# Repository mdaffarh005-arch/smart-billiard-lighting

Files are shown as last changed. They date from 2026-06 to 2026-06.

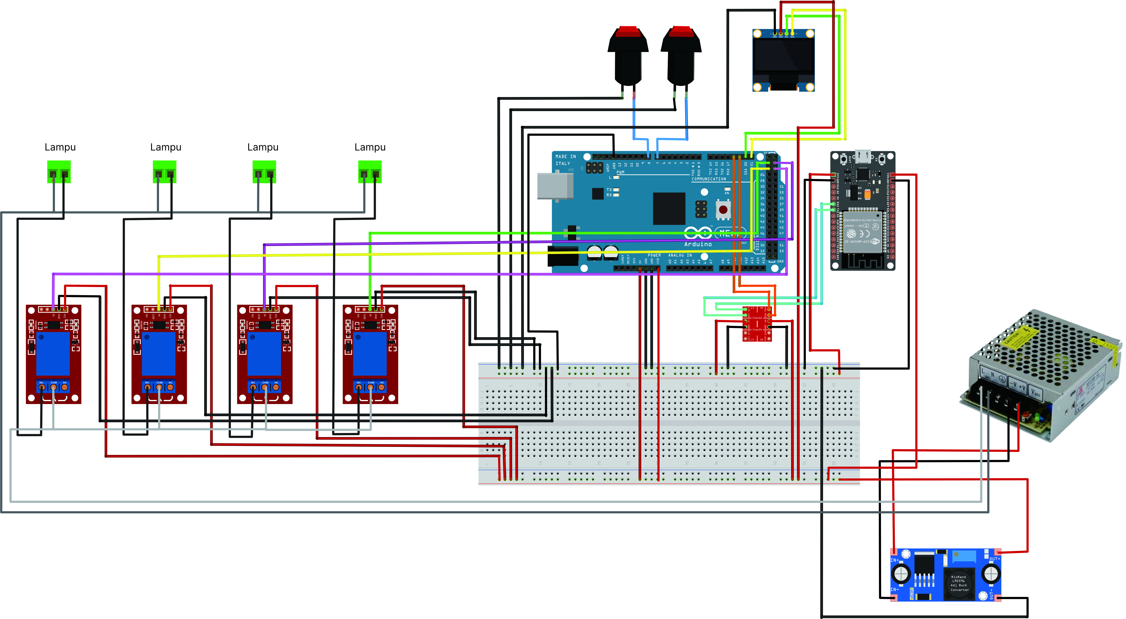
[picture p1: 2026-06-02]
Hardware/wiring-diagram-smart-billiard-lighting.jpg

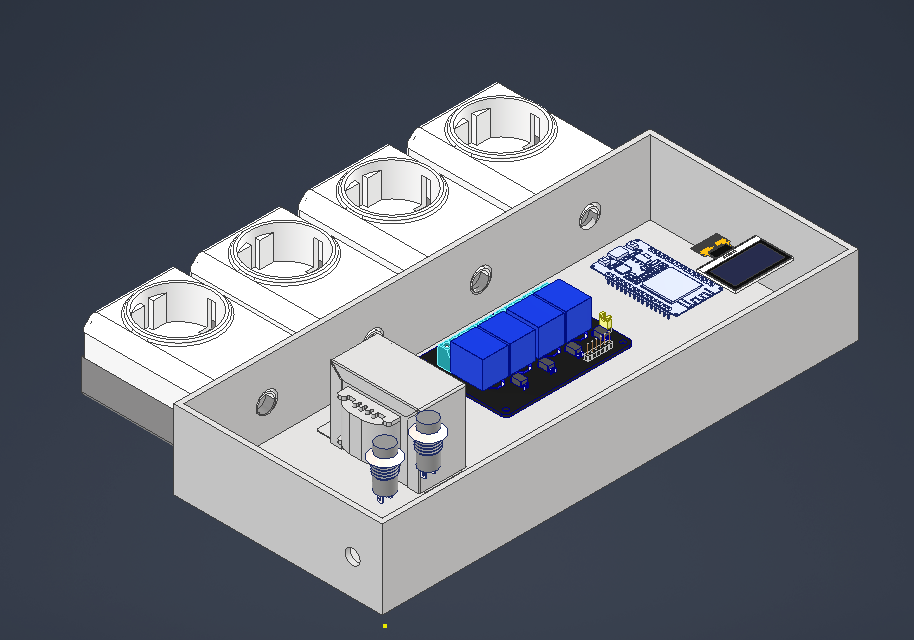
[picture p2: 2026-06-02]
3D Design/TOP Right Back Without Box Cover View.png

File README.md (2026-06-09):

# 🎱 Smart Billiard Lighting & Billing System

> Integrasi Billing, Timer, dan Kontrol Lampu dalam Satu Sistem

Sistem berbasis ATmega2560 yang mengintegrasikan kontrol lampu meja biliar, timer permainan, dan perhitungan biaya sewa dalam satu dashboard kasir. Proyek ini bertujuan meningkatkan efisiensi operasional, mengurangi human error, dan meminimalkan pemborosan energi listrik.

---

📖 Overview

Smart Billiard Lighting & Billing System merupakan solusi otomatisasi untuk membantu pengelolaan arena biliar. Sistem menghubungkan aplikasi kasir dengan mikrokontroler ATmega2560 melalui komunikasi serial UART sehingga status penggunaan meja dapat dipantau dan dikendalikan secara real-time.

Selain mengontrol lampu meja secara otomatis, sistem juga mampu mencatat durasi bermain, menghitung biaya sewa berdasarkan tarif per menit, serta menyimpan riwayat transaksi.

---

🎯 Objectives
* **Mengurangi pemborosan energi listrik pada meja biliar.**
* **Mengotomatisasi pencatatan durasi bermain pelanggan.**
* **Menghitung biaya sewa secara otomatis berdasarkan waktu penggunaan.**
* **Mengurangi human error dalam operasional arena biliar.**
* **Meningkatkan efisiensi pengelolaan meja dan transaksi kasir.**

✨ Features

⏱ Real-Time Timer

Menampilkan durasi bermain setiap meja secara real-time.

💰 Flexible Pricing

Harga per jam dapat diatur sesuai kebutuhan operasional.

🧮 Automatic Billing

Total biaya dihitung otomatis berdasarkan durasi penggunaan meja.

💡 Smart Lighting Control

Lampu meja menyala dan mati mengikuti status penggunaan meja.

🎛 Manual & Automatic Mode

Mendukung pengoperasian secara otomatis maupun manual.

📊 Monitoring Dashboard

Menampilkan status meja, durasi bermain, dan total biaya dalam satu tampilan.

💲Income Automatic Monitoring

Dapat menghitung otomatis total pendapatan yang didapatkan.

```mermaid
flowchart TD
    A[Kasir Dashboard]
    B[Serial Communication]
    C[ATmega2560]
    D[Timer]
    E[Billing]
    F[Relay]
    G[Durasi Bermain]
    H[Total Biaya]
    I[Lampu Meja]

    A --> B
    B --> C
    C --> D
    C --> E
    C --> F
    D --> G
    E --> H
    F --> I
```

Main Workflow
* **Kasir memilih meja yang akan digunakan.**
* **Kasir mengatur tarif per menit.**
* **Sistem mengaktifkan timer dan lampu meja.**
* **Durasi bermain dihitung secara real-time.**
* **Sistem menghitung biaya berdasarkan durasi bermain.**
* **Saat sesi berakhir, lampu dimatikan otomatis.**
* **Riwayat transaksi disimpan pada sistem.**

## 👥 Tim Pengembang & Kontributor

| No | Nama Lengkap | NRP | Peran Utama & Fokus Jobdesk | GitHub Profile | Status Kontribusi |
| :---: | :--- | :---: | :--- | :--- | :---: |
| **1** | **Muh. Daffa Rizaldy H.** | 2124600004 | **Project Manager**<br>• Manajemen linimasa & koordinasi integrasi sistem | [@mdaffarh005-arch](https://github.com/mdaffarh005-arch) | 🟢 Done Commit |
| **2** | **Moh Harudin Ali** | 2124600008 | **Software Engineer (Firmware)**<br>• Pengodean logika kontrol pemutusan relay | [@Harudin31](https://github.com/Harudin31) | 🟢 Done Commit |
| **3** | **Achmad Rafie Febriansyah** | 2124600011 | **3D Designer**<br>• Pemodelan objek 3D casing box komponen | [@rafiefebriansyahh](https://github.com/rafiefebriansyahh) | 🟢 Done Commit |
| **4** | **Imam Syaifudin** | 2124600015 | **Hardware Engineer**<br>• Perancangan skematik dan desain PCB | [@imam603](https://github.com/imam603) | 🟢 Done Commit |
| **5** | **Muhammad Abdi Muhyi Umam** | 2124600023 | **UI/UX Designer**<br>• Perancangan interface dashboard web kasir | [@abdiemuhyi](https://github.com/abdiemuhyi) | 🟢 Done Commit |
| **6** | **Gandhi Husain Albana** | 2124600026 | **Software Engineer (Web & DB)**<br>• Pengembangan database & komunikasi serial | [@gandhialbana-art](https://github.com/gandhialbana-art) | 🟢 Done Commit |

---

## 📊 To Do List

### 🟢 Complete

* **[x]Repository setup**
* **[x]Git workflow configuration**
* **[x]Initial system design**
* **[x]Initial system planning**
* **[x]Mind map & root cause analysis**
* **[x]Team collaboration setup**
* **[x]Dashboard development**
* **[x]Automatic billing calculation**
* **[x]Relay control integration**
* **[x]Hardware assembly**
* **[x]PCB design**

🌍 SDGs Impact

SDG 7 – Affordable and Clean Energy

Meningkatkan efisiensi penggunaan energi melalui sistem kontrol lampu otomatis.

SDG 12 – Responsible Consumption and Production

Mendorong penggunaan sumber daya listrik yang lebih efisien dan bertanggung jawab.

🛠 Development Tools

* **ATmega2560**
* **Wokwi Simulator**
* **VS Code**
* **GitHub**
* **EasyEDA**
* **Figma**
* **Python Tkinter**

📚 Course Information

* **Course: Microcontroller AVR**
* **Project Type: Embedded System & IoT Project**
* **Repository: Smart Billiard Lighting & Billing System**

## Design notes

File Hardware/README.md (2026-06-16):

# 💡 Smart Billiard Lighting

## 📂 Folder Hardware

# Isi Folder
- File Schematic (EasyEDA)
- File PCB Layout
- 3D PCB View
- Wiring Diagram (Fritzing)

# Arduino Mega 2560
Berfungsi sebagai pengendali utama sistem:
- Mengelola logika program billing
- Mengontrol relay lampu meja biliar
- Membaca input tombol ON/OFF
- Mengirim dan menerima data dengan ESP32
- Mengendalikan tampilan OLED

# ESP32 DevKitC
Digunakan sebagai modul komunikasi:
- Koneksi Wi-Fi ke aplikasi atau server
- Monitoring status sistem secara real-time
- Pertukaran data dengan Arduino Mega melalui UART

# Logic Level Converter
Digunakan untuk menyesuaikan level tegangan komunikasi:
- Konversi sinyal 5V ↔ 3.3V
- Melindungi ESP32 dari level tegangan Arduino Mega

# Relay Module 1 Channel
Digunakan untuk mengendalikan lampu meja biliar:
- Relay 1 → Lampu Meja 1
- Relay 2 → Lampu Meja 2
- Relay 3 → Lampu Meja 3
- Relay 4 → Lampu Meja 4
- Isolasi antara rangkaian kontrol dan beban lampu

# OLED Display SSD1306
Berfungsi sebagai tampilan informasi sistem:
- Status koneksi
- Informasi billing
- Waktu bermain
- Status lampu meja

# Push Button
Digunakan sebagai kontrol manual:
- Tombol ON untuk mengaktifkan sistem atau fungsi tertentu
- Tombol OFF untuk menghentikan atau membatalkan proses

# Power Supply
Rangkaian catu daya terdiri dari:
- Input tegangan 12V DC

# Modul step-down LM2596
- Output 5V untuk Arduino, relay, dan periferal
- Output 3.3V untuk ESP32 dan rangkaian logika

# Koneksi Sistem
- Komunikasi Arduino Mega ↔ ESP32
- TX2 Arduino (D16) → RX2 ESP32 melalui Level Converter
- RX2 Arduino (D17) → TX2 ESP32 melalui Level Converter
- Komunikasi menggunakan protokol UART Serial
  
OLED Display
- SDA → D20 (SDA)
- SCL → D21 (SCL)
Menggunakan komunikasi I2C

Input Push Button
- Tombol ON → D7
- Tombol OFF → D8
  
Output Relay
- Relay 1 → D22
- Relay 2 → D23
- Relay 3 → D24
- Relay 4 → D25

# Desain PCB
PCB dirancang untuk:
- Mengintegrasikan seluruh komponen dalam satu board
- Mempermudah instalasi dan perawatan sistem
- Mengurangi penggunaan kabel eksternal
- Menyediakan konektor terminal untuk beban lampu dan catu daya

# 3D View
Visualisasi 3D digunakan untuk:
- Memverifikasi posisi komponen
- Memastikan tidak terjadi benturan antar komponen
- Membantu proses fabrikasi dan perakitan PCB

# Wiring Diagram (Fritzing)
- Diagram wiring digunakan sebagai panduan:
- Penyambungan antar modul
- Identifikasi pin koneksi
- Referensi perakitan prototipe sebelum PCB diproduksi

# Tools
- EasyEDA
- Fritzing

## Designer
Imam Syaifudin/2124600015

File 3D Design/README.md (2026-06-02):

# 3D Design

Folder ini berisi desain mekanik dan model 3D dari sistem Smart Billiard Lighting.

## Isi Folder

- File Assembly Autodesk Inventor
- Tampak Atas (Top View)
- Tampak Depan (Front View)
- Tampak Samping Kiri (Left View)
- Tampak Samping Kanan (Right View)
- Tampak Belakang Kanan Tanpa Cover
- Tampak Atas Tanpa Cover
- Dokumentasi Render Desain
## Deskripsi Desain

### Smart Billiard Lighting

Desain ini digunakan sebagai housing dan struktur utama sistem pencahayaan meja biliar pintar.

Fitur desain:

- Dudukan lampu LED
- Ruang pemasangan komponen elektronik
- Jalur kabel internal
- Struktur penutup (cover)
- Sistem pemasangan di atas meja biliar
- Desain modular untuk memudahkan perawatan
## Tujuan Desain

Desain dibuat untuk:

- Menyediakan pencahayaan merata pada meja biliar
- Mempermudah pemasangan perangkat elektronik
- Meningkatkan estetika meja biliar
- Memudahkan proses maintenance
## Komponen Utama

### Frame Utama

Berfungsi sebagai rangka penopang seluruh sistem.
### Cover Atas

Digunakan untuk melindungi komponen elektronik dari debu dan benturan ringan.

### Dudukan Lampu

Sebagai tempat pemasangan lampu LED untuk pencahayaan meja biliar.
### Housing Elektronik

Digunakan untuk menempatkan:

- Arduino
- Power Supply
- Modul Relay
- Sensor pendukung
## Software

- Autodesk Inventor
- Autodesk Fusion 360 (Opsional)
## Dokumentasi View

Folder ini menyediakan beberapa sudut pandang desain:

- TOP View
- FRONT View
- LEFT View
- RIGHT View
- TOP Without Box Cover View
- TOP Right Back Without Box Cover View
## 3D Designer

Achmad Rafie Febriansyah

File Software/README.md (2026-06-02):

# 💡 Smart Billiard Lighting

## 📂 Folder Software
Berisi source code utama untuk mengontrol sistem pencahayaan meja biliar.

---

## 🔧 Hardware Setup (Wokwi Diagram)

### Komponen Utama
- **Arduino Mega 2560**
- **ESP32 Devkit V1**
- **Breadboard Half**
- **4 LED merah (L1–L4)** dengan resistor 220Ω
- **2 Push Button** (hijau = ON/OFF, biru = kontrol tambahan)
- **OLED SSD1306 (I2C, address 0x3C)** untuk monitor status

### 📑 Koneksi Penting
- LED1 → Pin 22 (via resistor 220Ω)  
- LED2 → Pin 23 (via resistor 220Ω)  
- LED3 → Pin 24 (via resistor 220Ω)  
- LED4 → Pin 25 (via resistor 220Ω)  
- OLED SCL → Pin 21 (Arduino Mega)  
- OLED SDA → Pin 20 (Arduino Mega)  
- ESP32 RX0 ↔ Arduino Mega Pin 18  
- ESP32 TX0 ↔ Arduino Mega Pin 19  
- Push Button hijau → Pin 7 (Mega)  
- Push Button biru → Pin 6 (Mega)  
- Semua GND terhubung ke rail negatif breadboard  
- VCC OLED terhubung ke 5V rail breadboard  

---

## 📊 Fungsi Sistem
- Tombol **hijau**: start sistem.  
- Tombol **biru**: stop sistem.  
- **OLED**: menampilkan status sistem meja yang aktif (lampu aktif, mode, dll).  
- **ESP32**: komunikasi serial dengan Arduino Mega untuk integrasi IoT.  

---
## 🚀 Fitur Sistem

✅ Kontrol 4 meja biliar independen

✅ Monitoring OLED real-time

✅ Tombol Start dan Emergency

✅ Komunikasi Serial Mega ↔ ESP32

✅ Integrasi GUI Desktop

✅ Dukungan IoT dan MQTT

✅ Status meja real-time

✅ Update otomatis setiap detik

---
---
## 🎯 Tujuan Sistem

Smart Billiard Lighting dirancang untuk:

- Mengotomatisasi pengoperasian meja biliar.
- Memudahkan operator dalam mengontrol lampu meja.
- Menampilkan status meja secara real-time.
- Menyediakan fitur Emergency Stop.
- Mendukung integrasi IoT melalui ESP32.
- Mengurangi kesalahan operasional manual.

---

## 📌 Catatan
- File `diagram.json` adalah blueprint rangkaian di Wokwi.  
- Pastikan library **Adafruit SSD1306** dan **Wire** sudah terpasang di Arduino IDE.  
- ESP32 bisa digunakan untuk koneksi WiFi/MQTT agar sistem bisa dikontrol jarak jauh.

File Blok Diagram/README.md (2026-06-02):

Technical Solution
1. Integrasi Sistem
    - Aplikasi kasir terhubung dengan ATmega2560 melalui UART Serial.
    - Status meja dikendalikan dari dashboard kasir.
2. Otomatisasi Proses
    - Timer dan perhitungan biaya berjalan secara real-time.
    - Lampu meja mengikuti status permainan secara otomatis.
3. Kontrol Aktuator
    - Relay 5V digunakan untuk mengendalikan lampu meja biliar.
    - Mendukung mode otomatis dan manual.

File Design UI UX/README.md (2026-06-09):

# Design UI UX

Folder ini berisi desain antarmuka (UI/UX) aplikasi Smart Billiard Lighting.

## Isi Folder

- File Figma
- Mockup Desktop
- Asset Icon
- Screenshot Progress

## Halaman

### Dashboard
Menampilkan informasi utama sistem:
- Status lampu
- Mode sistem
- Nomor meja aktif
- Countdown waktu
- Status koneksi Arduino
- Log sistem

### Billing
Digunakan untuk pengelolaan penyewaan meja:
- Pemilihan meja
- Pemilihan durasi bermain
- Perhitungan tarif
- Mulai billing
- Tambah waktu
- Selesai billing
- Monitoring billing aktif

## Tools

- Figma
- FigJam

## UI Designer

Muhammad Abdi Muhyi Umam

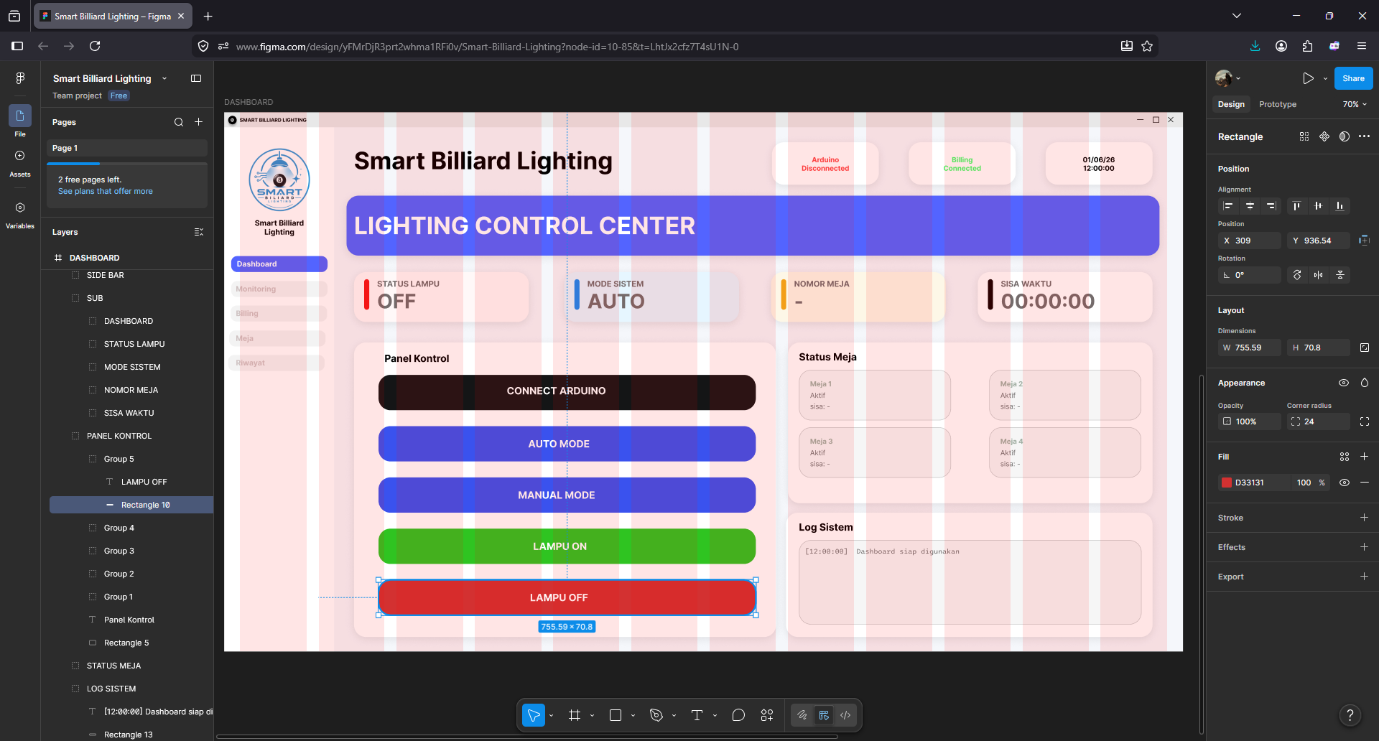
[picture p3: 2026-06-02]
Design UI UX/Screenshot/screenshot-dashboard.png

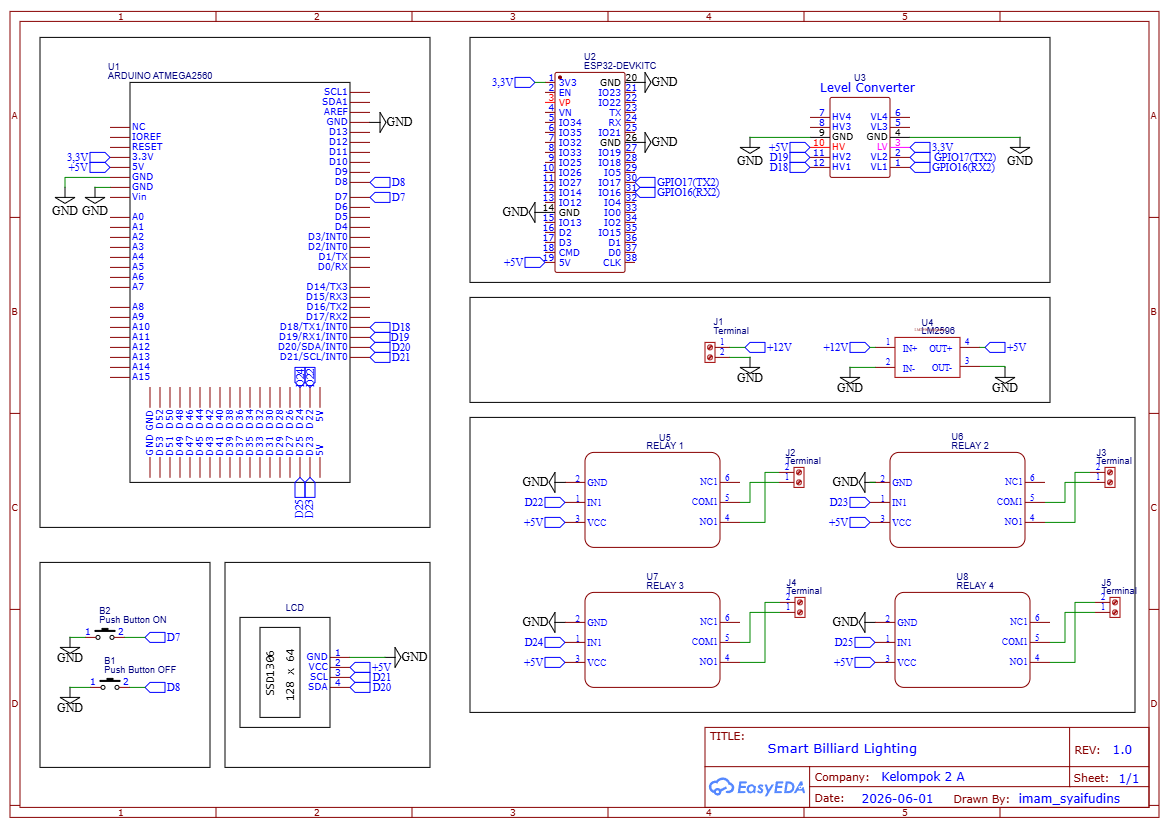
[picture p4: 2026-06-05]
Hardware/Schematic-PCB-smart-biliard-lighting.png

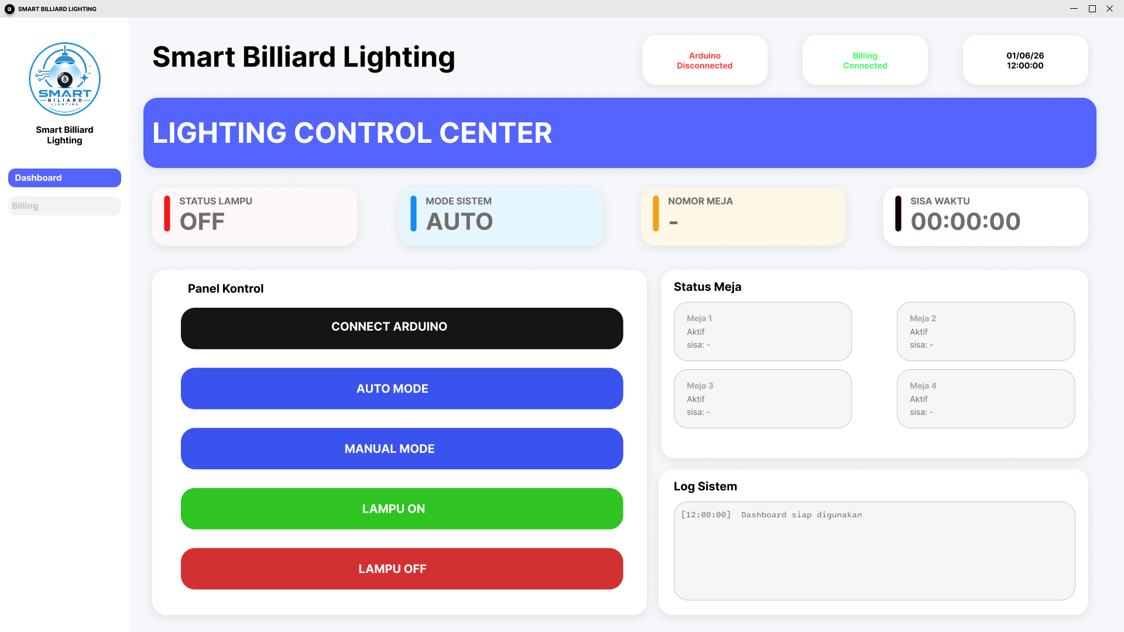
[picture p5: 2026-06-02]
Design UI UX/Screenshot/DASHBOARD.png

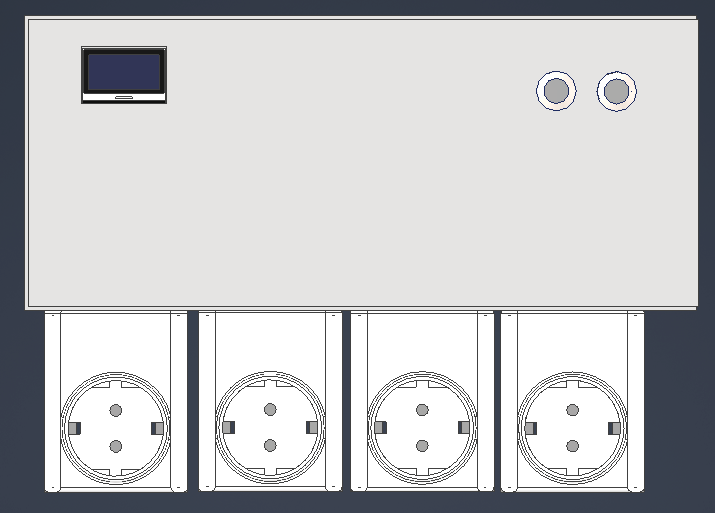
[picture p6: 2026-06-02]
3D Design/TOP View.png

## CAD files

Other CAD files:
3D Design/Smart Billiard Lighting.iam

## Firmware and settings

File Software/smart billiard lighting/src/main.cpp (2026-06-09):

#include <Arduino.h>

extern "C"
{
    #include "gpio.h"
    #include "uart.h"
    #include "timer.h"
    #include "billiard.h"
}

#include "oled.h"

char serialBuffer[64];
uint8_t serialIndex = 0;

uint32_t oledUpdateTimer = 0;
uint32_t serialUpdateTimer = 0;

void setup()
{
    GPIO_Init();

    UART_Init(9600);

    Timer_Init();

    OLED_Init();

    Billiard_Init();

    UART_SendString("SMART_BILLIARD_READY\r\n");
}

void loop()
{
    if(!systemEnabled)
    {
        if(StartButtonPressed())
        {
            delay(50);

            if(StartButtonPressed())
            {
                systemEnabled = true;

                UART_SendString("SYSTEM_ON\r\n");

                while(StartButtonPressed());
            }
        }
    }

    if(EmergencyButtonPressed())
    {
        stopAllTables();

        systemEnabled = false;

        UART_SendString("EMERGENCY\r\n");

        delay(300);

        while(EmergencyButtonPressed());
    }

    while(UART_Available())
    {
        char c = UART_ReadChar();

        if(c == '\r')
            continue;

        if(c == '\n')
        {
            serialBuffer[serialIndex] = '\0';

            processCommand(serialBuffer);

            serialIndex = 0;
        }
        else
        {
            if(serialIndex < sizeof(serialBuffer) - 1)
            {
                serialBuffer[serialIndex++] = c;
            }
        }
    }

    updateTables();

    if(millis() - oledUpdateTimer >= 500)
    {
        oledUpdateTimer = millis();

        drawOLED();
    }

    if(millis() - serialUpdateTimer >= 1000)
    {
        serialUpdateTimer = millis();

        sendStatusToGUI();
    }
}

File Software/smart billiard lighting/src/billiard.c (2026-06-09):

#include "billiard.h"
#include "gpio.h"
#include "uart.h"
#include "timer.h"

#include <stdio.h>
#include <stdlib.h>
#include <string.h>

TableData tables[4];

bool systemEnabled = false;

void stopTable(uint8_t index)
{
    tables[index].active = false;
    tables[index].remainSec = 0;
    tables[index].endTime = 0;

    Relay_Off(index);

    char buffer[32];
    sprintf(buffer, "TIMEUP:%d\r\n", index + 1);
    UART_SendString(buffer);
}

void stopAllTables(void)
{
    for(uint8_t i = 0; i < 4; i++)
    {
        Relay_Off(i);

        tables[i].active = false;
        tables[i].remainSec = 0;
        tables[i].endTime = 0;
    }
}

void startTable(uint8_t index, uint16_t minutes)
{
    if(index > 3)
        return;

    tables[index].active = true;
    tables[index].remainSec = (uint32_t)minutes * 60UL;
    tables[index].endTime = millis() + ((uint32_t)minutes * 60000UL);

    Relay_On(index);
}

void Billiard_Init(void)
{
    stopAllTables();
}

void processCommand(char *cmd)
{
    if(cmd == NULL)
        return;

    if(strncmp(cmd, "ON:", 3) == 0)
    {
        int meja = atoi(cmd + 3);

        if(meja >= 1 && meja <= 4)
        {
            uint8_t index = meja - 1;

            Relay_On(index);

            tables[index].active = true;
            tables[index].remainSec = 0;
            tables[index].endTime = 0;

            char buffer[32];
            sprintf(buffer, "LAMP_ON:%d\r\n", meja);
            UART_SendString(buffer);
        }
    }

    else if(strncmp(cmd, "OFF:", 4) == 0)
    {
        int meja = atoi(cmd + 4);

        if(meja >= 1 && meja <= 4)
        {
            uint8_t index = meja - 1;

            Relay_Off(index);

            tables[index].active = false;
            tables[index].remainSec = 0;
            tables[index].endTime = 0;

            char buffer[32];
            sprintf(buffer, "LAMP_OFF:%d\r\n", meja);
            UART_SendString(buffer);
        }
    }

    else if(cmd[0] == 'M')
    {
        char *comma = strchr(cmd, ',');

        if(comma)
        {
            int meja = atoi(cmd + 1);
            int menit = atoi(comma + 1);

            if(meja >= 1 && meja <= 4)
            {
                startTable(meja - 1, menit);

                char buffer[32];
                sprintf(buffer, "START:%d:%d\r\n", meja, menit);
                UART_SendString(buffer);
            }
        }
    }

    else if(strncmp(cmd, "STOP", 4) == 0)
    {
        char *comma = strchr(cmd, ',');

        if(comma)
        {
            int meja = atoi(comma + 1);

            if(meja >= 1 && meja <= 4)
            {
                stopTable(meja - 1);
            }
        }
    }

    else if(strcmp(cmd, "RESET") == 0)
    {
        stopAllTables();
    }

    else
    {
        char buffer[64];
        sprintf(buffer, "UNKNOWN_CMD:%s\r\n", cmd);
        UART_SendString(buffer);
    }
}

void updateTables(void)
{
    uint32_t now = millis();

    for(uint8_t i = 0; i < 4; i++)
    {
        if(tables[i].active && tables[i].endTime > 0)
        {
            if(now >= tables[i].endTime)
            {
                stopTable(i);
            }
            else
            {
                tables[i].remainSec = (tables[i].endTime - now) / 1000UL;
            }
        }
    }
}

void sendStatusToGUI(void)
{
    char buffer[64];

    for(uint8_t i = 0; i < 4; i++)
    {
        sprintf(
            buffer,
            "T%d:%s:%lu\r\n",
            i + 1,
            tables[i].active ? "ON" : "OFF",
            (unsigned long)tables[i].remainSec
        );

        UART_SendString(buffer);
    }

    sprintf(
        buffer,
        "SYSTEM:%s\r\n",
        systemEnabled ? "READY" : "OFF"
    );

    UART_SendString(buffer);
    UART_SendString("---\r\n");
}

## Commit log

2026-05-30 Simplify task board layout under To Do List header
2026-06-02 wiring diagram
2026-06-02 hapus bagian arsitektur kasir di readme
2026-06-02 wiring biliad
2026-06-02 Revise Imam Syaifudin's role description in README
    Updated the role description for Imam Syaifudin to reflect schematic design and PCB layout.
2026-06-02 Rename smart billiard.png to wiring-diagram-smart-billiard-lighting.png
